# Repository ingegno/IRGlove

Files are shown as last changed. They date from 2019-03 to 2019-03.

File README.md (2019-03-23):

# IRGlove

Hier beschrijven een adaptatie van het GloveIR project van Phablabs: een handschoen om IR bestuurbare toestellen te controleren.

**English**: See [English Manual](README_EN.md) - Here we describe an adaptation of the GloveIR project of Phablabs: a glove to control IR enabled devices

## Base project

Het originele phablabs project vindt je hier terug: 

* [Phablabs.eu ir-glove project](http://phablabs.eu/workshop/ir-glove)
* [PDF Constructie handleiding](http://phablabs.eu/sites/default/files/Photonics%20IRglove_online_0.pdf)

De Code is gebaseerd op `record.ino` van [IRLib2](https://github.com/cyborg5/IRLib2) welke GPL v3 is, dus deze handleiding is ook onder Licentie GPL v3.

## Constructie
We doen volgende wijzigingen tov het Phalabs project
* gebruik Arduino Nano
* gebruik Arduino Nano houder
* componenten bevestigen rechtstreeks aan de Nano houder
* stand-alone versie: handschoen kan IR opnemen en afspelen zonder dat een PC nodig is

# Handleiding

## Constructie op Breadboad
Maak indien gewenst eerst de constructie op een breadboard. Daarna kun je al de code flashen naar de Arduino, en testen.

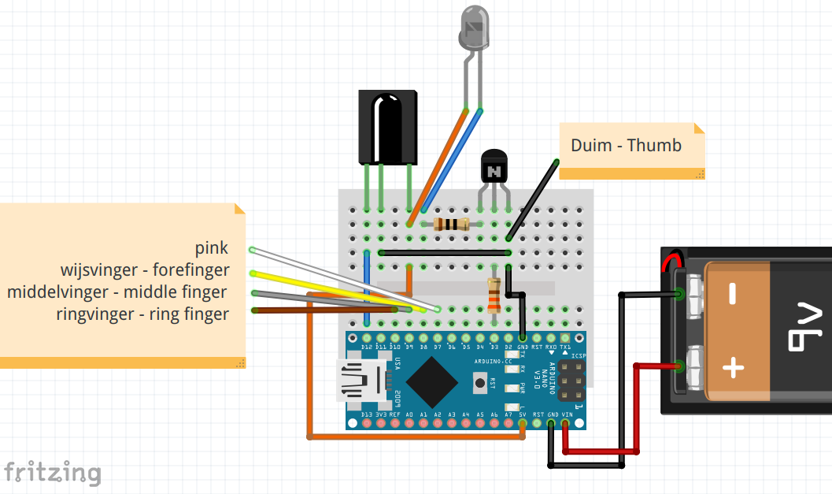
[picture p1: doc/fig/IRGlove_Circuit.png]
circuit


## Constructie Foto Handleiding

### Electronisch circuit

We beginnen met de electronica klaarmaken. 

**Stap 1** 

Plaats de Nano op de Nano houder. Zorg dat pinnen juist zitten !

Maak draden die met de handschoen zullen verbinden voor de 5 fingers. Connecteer dan als volgt

* duim: GND zoals op foto
* wijsvinger: D10
* middelvinger: D9
* ringvinger: D8
* pink: D7

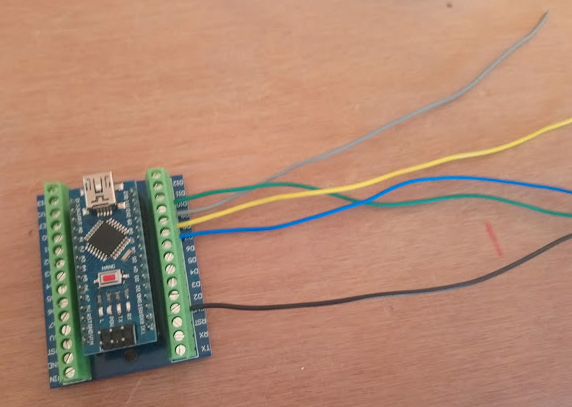
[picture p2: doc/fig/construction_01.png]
stap01


**Stap 2** 

De 9V batterijhouder connecteer je met Vin en GND aan de andere kant. Opgelet, Vin is **ROOD**.

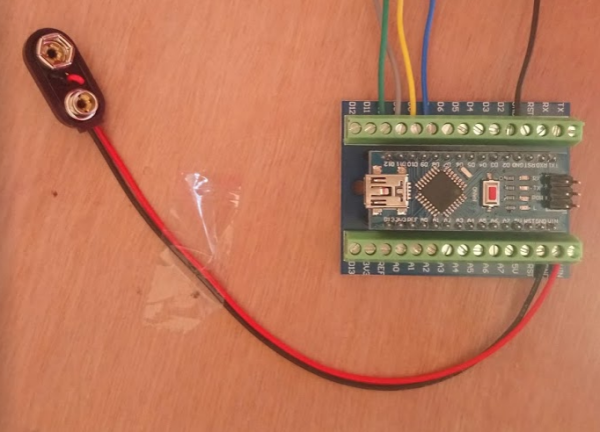
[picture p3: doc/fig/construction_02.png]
stap02


**Stap 3** 

Soldeer de 330 Ohm weerstand aan middelste beentje van de transistor zoals op de foto. Dus, aan de platte kant
van de transistor!

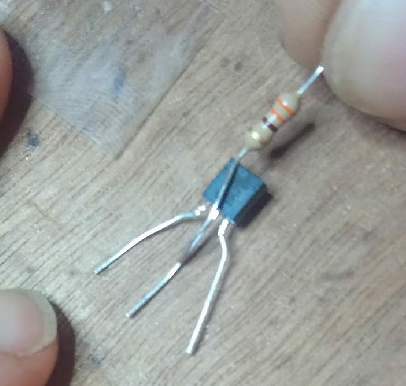
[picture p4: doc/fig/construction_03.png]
stap03


**Stap 4** 

Bescherm nu middelste beentje transistor met een krimpkous.

Aan de *linkerkant* (als je kijkt op platte kant transistor) soldeer je de 10 Ohm weerstand. En daaraan dan een draad
die lang genoeg is om tot aan de knokels van je hand te lopen.

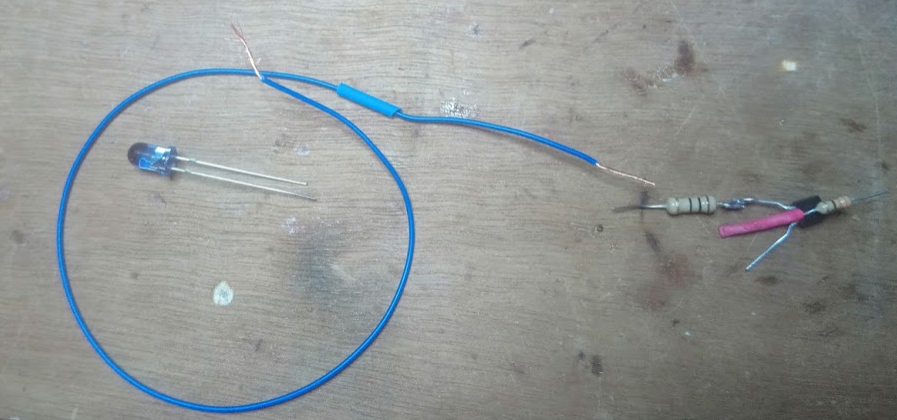
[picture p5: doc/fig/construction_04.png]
stap04


**Stap 5** 

Soldeer einde van die draad nu aan **korste** beentje van de IR LED (onze *zender*). Bescherm met krimpkous.

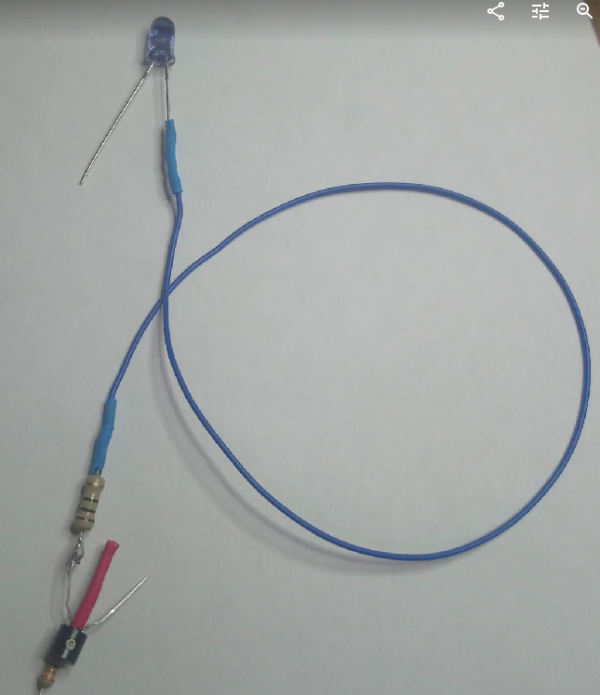
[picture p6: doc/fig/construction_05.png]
stap05


Het lange beentje van de IR LED is de +. Neem dan ook een **rode** draad, en soldeer hem eraan. Knip beentje LED
eerst wat korter dat je niet teveel krimpkous nodig hebt

**Stap 6** 

De rode draad van de IR LED stop je in de 5V van de NANO houder **samen** met **rechter** been van de IR ontvanger
(rechts als je kijkt naar de uitstulping).

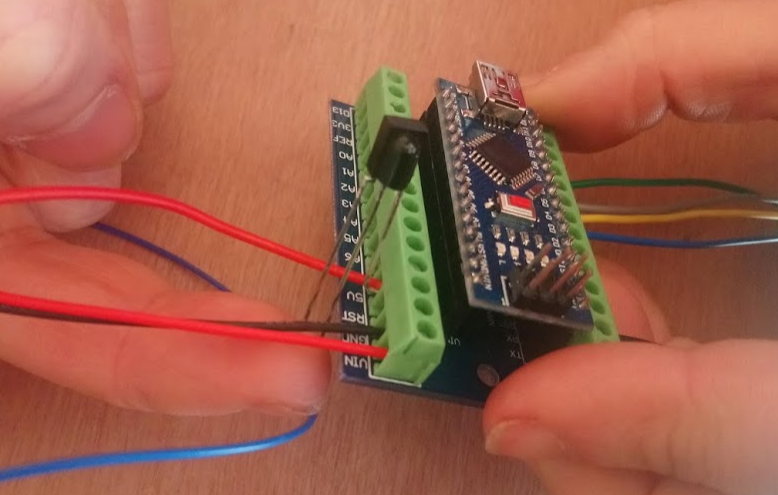
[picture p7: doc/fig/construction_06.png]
stap06


**Stap 7** 

Om kortsluiting te vermijden, doe krimpkous over bovenkant van middelste been IR ontvangen, en stop deze dan, na 
plooien in de GND van de Arduino houder

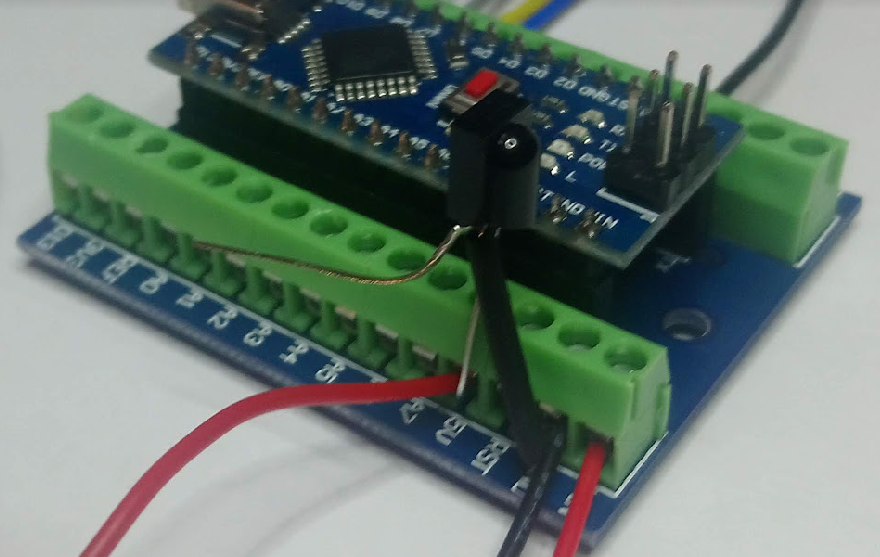
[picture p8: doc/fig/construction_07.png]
stap07


Buig linkse been IR ontvanger naar achter.

**Stap 8** 

Soldeer een draad aan linkse been IR ontvanger, en bevestig andere uiteinde aan pin D12.

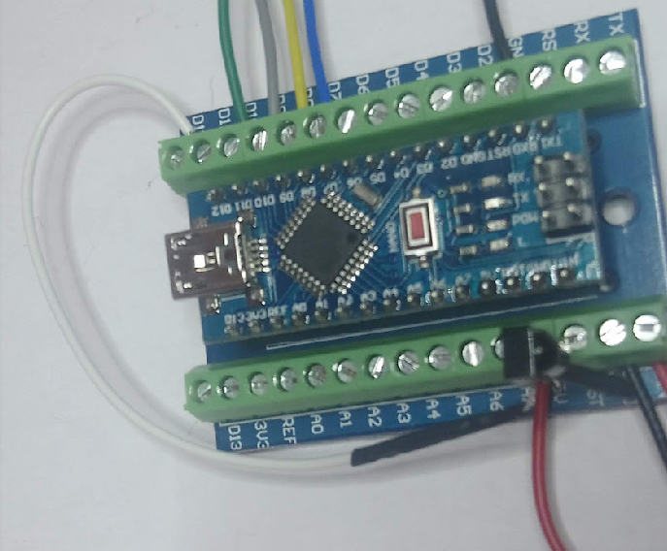
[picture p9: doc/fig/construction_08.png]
stap08


**Stap 9** 

Je hebt nu enkel nog de transistor die los zit. De *rechterkant* (als je kijkt op platte kant transistor) van de 
transistor moet in de GND, terwijl uiteinde van de 330 Ohm weerstand in pin D3 moet. Dat moet normaal
lukken zoals op volgende foto:

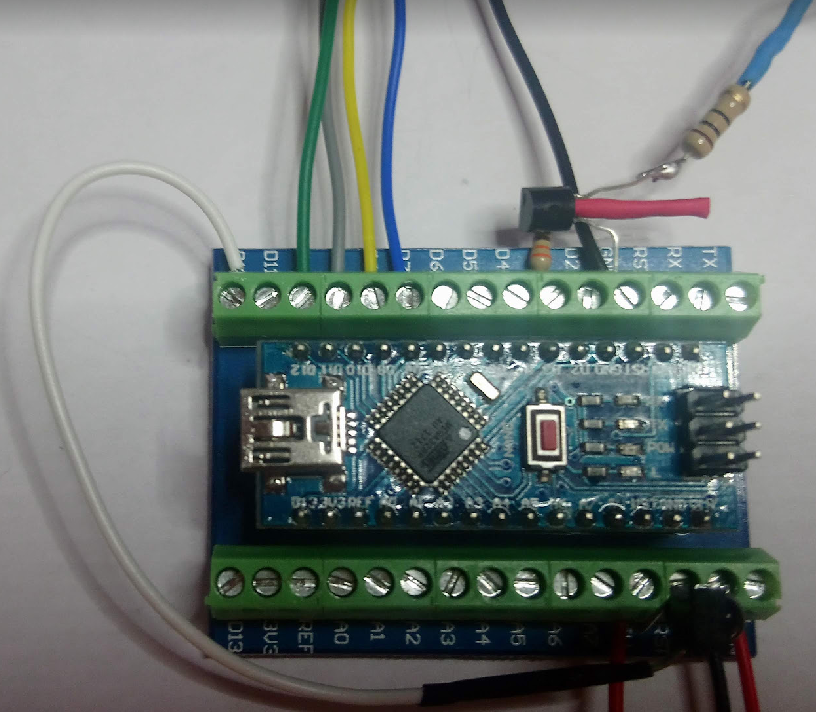
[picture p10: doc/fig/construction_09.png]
stap09


**Stap 10**
Je circuit is af. We moeten nu de vingers bevestigen aan de handschoen, en de IR LED plaatsen waar we signalen 
willen uitsturen. Het geheel zou er als volgt uit moeten zien:

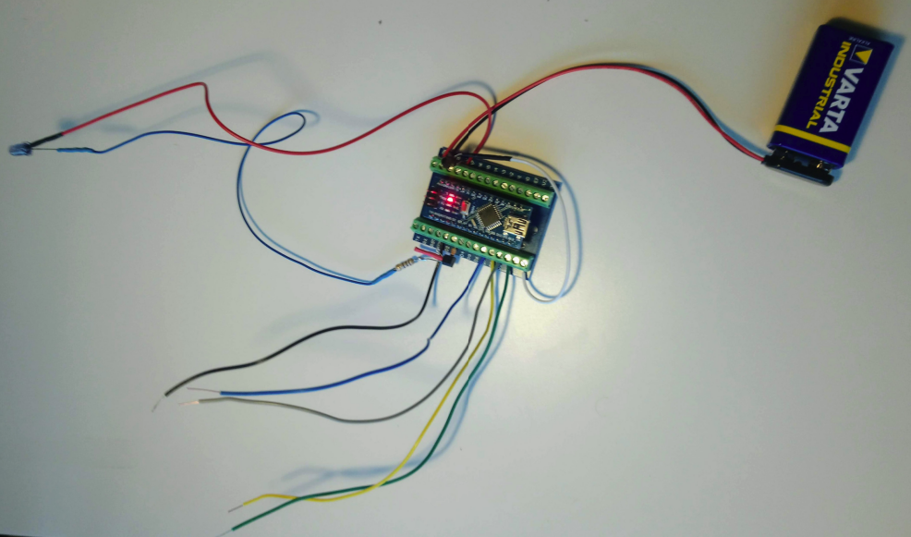
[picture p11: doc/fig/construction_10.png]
stap10


### Handschoen

De handschoen kun je nu maken of eerst de code installeren om te testen.

## Code Installeren

### Benodigdheden
Installeer op je computer de Arduino IDE 1.8.8. 

Installeer dan via de library manager (`CTRL+SHIFT+I`) volgende bibliotheek:
* EEPROMEx versie 1.0.0 van Thijs Elenbaas

Install EEPROMex

Vervolgens download via deze link [IRLib2](https://github.com/cyborg5/IRLib2) via de **Download Zip** knop (Wij gebruiken versie 3 Jun 2018). VOEG HIER SCREENSHOT TOE
Unzip de download, en kopieer **een deel** van de Download naar de Arduino library folder zodat deze volgende structuur heeft: 

    Arduino/libraries/IRLib2
    Arduino/libraries/IRLibFreq
    Arduino/libraries/IRLibProtocols
    Arduino/libraries/IRLibRecv
    Arduino/libraries/IRLibRecvPCI

Op Windows is dit normaal in locatie `C:\Users\USERNAME\Documents\Arduino`, op linux in `\home\USERNAME\Arduino`.

### IRGlove code - Standaard Code
#### Installatie
Download de code van deze git via de **Download zip** knop en unzip de download. 
Dubbel klik op de `IRGlove-master/IRGlove/IRGlove.ino` file in de unzipped code folder. Dit zal Arduino 1.8.8 openen op onze code. 

Selecteer als bord Arduino Nano. Druk op compileer om te code te verifieren. 

Krijg je de fout:

    lto1: internal compiler error: in lto_output_varpool_node, at lto-cgraph.c:624
    Please submit a full bug report,
    with preprocessed source if appropriate.

dan dien je oplossing uit [deze thread](https://forum.arduino.cc/index.php?topic=574020.0) uit te voeren als gevolg van bug [39](https://github.com/arduino/ArduinoCore-avr/issues/39):

    Tools > Board > Boards Manager
    Wait for downloads to finish. WAT IS DIT WACHTEN????
    When you move the mouse pointer over "Arduino AVR Boards", you will see a "Select version" dropdown menu appear. Select "1.6.21". SCREENSHOT
    Click "Install".
    Wait for installation to finish.
    Click "Close".

Na dit project kun je opnieuw de laatste versie van de *Arduino AVR Boards* installeren.

Laad de code op je Arduino Nano.

#### Werking Code
De code werkt volgens een *state machine*, in het Nederlands *Eindigetoestandsautomaat*. Is het de eerste keer dat je de code oplaad, dan moet je nog programmeren wat de vingers moeten doen. 

De toestanden van de code zijn als volgt:

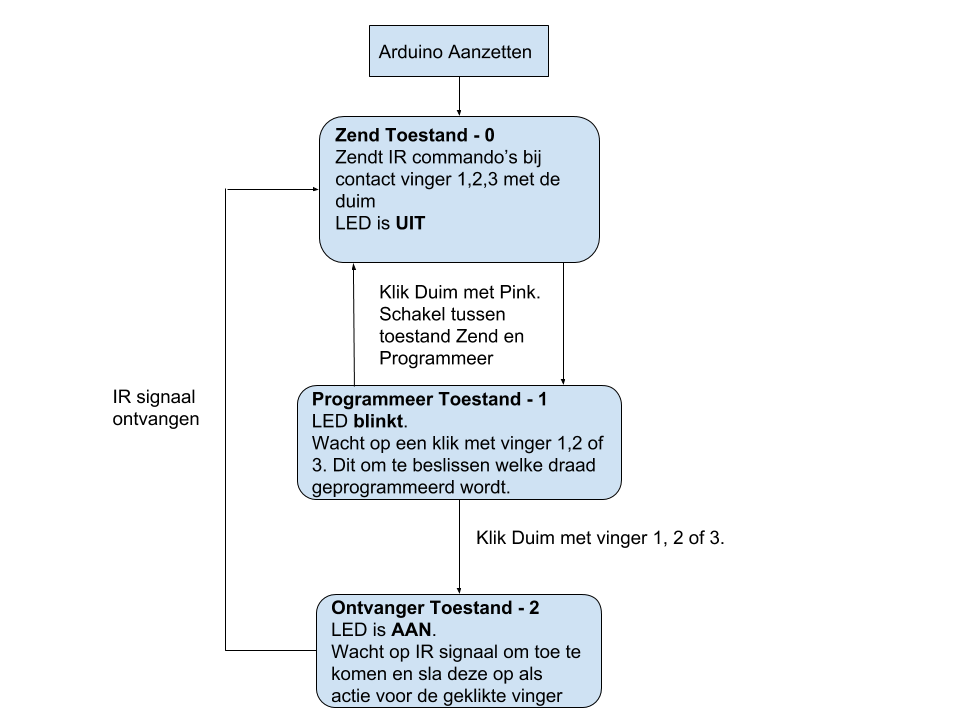
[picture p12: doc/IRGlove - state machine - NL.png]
finite state machine


Je gebruikt dus de pink (verbonden aan pin 7 van de Arduino) om tussen de toestanden te schakelen, kiest de vinger die je wil programmeren, en stuurt een IR bericht om dit op te slaat. Kijk naar de interne LED om te weten in welke toestand de Arduino Nano zich bevindt.

De LED is uit in de normale werking als codes uitgestuurd worden. Dit betekend dat enkel de POWER LED brandt:

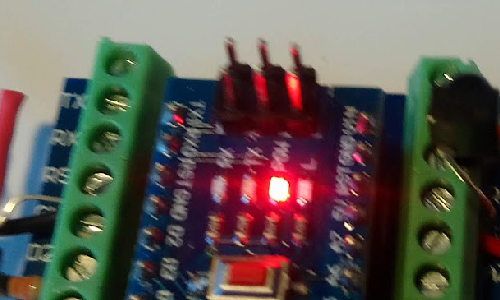
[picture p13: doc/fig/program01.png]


Terwijl gewacht wordt om een vinger te kiezen om te programmeren flikkert de LED aan en uit. Als er gewacht wordt op een IR code van een telecommando, zal de LED aan zijn.

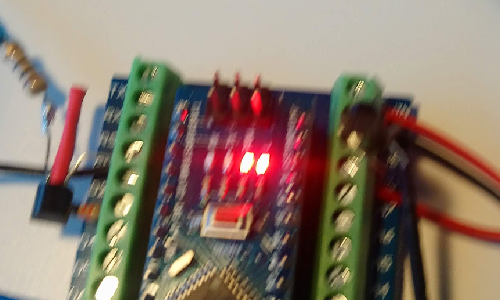
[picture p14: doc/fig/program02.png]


Zodra een code ontvangen is, schakelt de LED weer uit.

Wil je weten hoe deze eindigetoestandsautomaat geprogrammeerd werd? De basis werd in onze blokkencode gemaakt en dan geintegreerd in de code. Je kan de automaat bekijken via [onze blokkencode](http://blokkencode.ingegno.be/) waar je volgende xml moet opladen: [ProgramStates.xml](doc/ProgramStates.xml)

### IRGlove code - Test Code
#### Installatie
Download de code van deze git via de **Download zip** knop en unzip de download. 
Dubbel klik op de `IRGlove-master/IRGlove_SerialProgrammed/IRGlove_SerialProgrammed.ino` file in de unzipped code folder. Dit zal Arduino 1.8.8 openen op onze code. 

Selecteer als bord Arduino Nano. Druk op compileer om te code te verifieren. 

Krijg je de fout:

    lto1: internal compiler error: in lto_output_varpool_node, at lto-cgraph.c:624
    Please submit a full bug report,
    with preprocessed source if appropriate.

volg dan de oplossing hierboven gegeven bij standaard code.

#### Werking
Bij de test code hou je de Arduino Nano verbonden met de PC, en open je de Seriele monitor. Je kan via de seriele monitor de opdracht doorgeven om IR signalen op te slaan. Je krijgt feedback op de seriele monitor van ontvangen IR codes en uitgestuurde IR codes. Dit helpt je in begrijpen of een bepaalde IR code correct geinterpreteerd wordt door de code.

Merk op dat dit deel van de code ook beschikbaar is in de standaard code. Om de seriele monitor aan te schakelen voor de standaard code dien je enkel volgende lijn te zoeken in de `.ino` file

    // set serial output on or off
    #define TEST_WITH_SERIAL false

en wijzigen in 

    // set serial output on or off
    #define TEST_WITH_SERIAL true

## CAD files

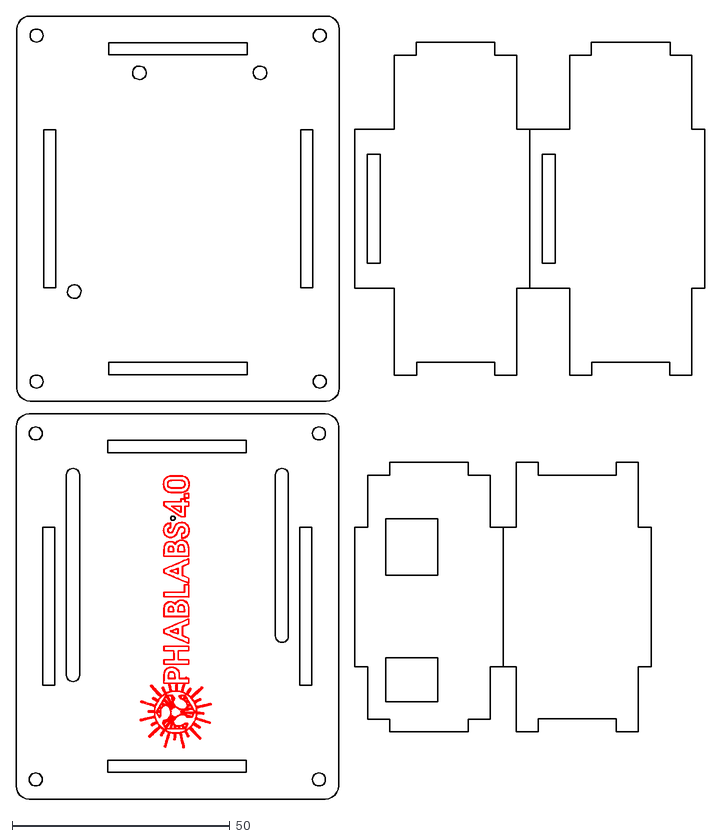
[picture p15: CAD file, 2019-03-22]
case/gloveIR case_UNO.dxf
158.2 x 179.9

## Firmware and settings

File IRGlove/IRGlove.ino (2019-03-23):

/* Based on record.ino Example sketch from IRLib2 - GPL v3
 *  Adapted by VUB http://phablabs.eu/workshop/ir-glove 
 *  Adapted by Ingegno Maker Space in https://github.com/ingegno/IRGlove:
 *      - fix bugs
 *      - correct store of signals
 *      
*/

/*  USER SETTINGS 
 *   
*/
// board selection
#define B_UNO 0
#define B_NANO 1
// do you use an UNO or a NANO for the glove ? 
#define IRGLOVE_BOARD B_NANO

// select language
#define LANG_EN 0
#define LANG_NL 1
// select language of the output in serial monitor
#define LANG_OUTPUT LANG_NL

// set the fingers you will use
const int COUNT = 3;
const String vinger_EN[COUNT] = {"forefinger", "middle finger", "ring finger"};
const String vinger[COUNT] = {"wijsvinger", "middelvinger", "ringvinger"};
// pins on the Arduino for the fingers:
const int INPUTS[COUNT] = {8, 9, 10};

// optional pin to program
const int PROGRAM_PIN = 7;

// pin used by the IR receiver
const int IR_RECEIVE_PIN = 12;

// pin used by the IR sender is based on your hardware. UNO and NANO are pin 3
// for other boards look up the pin in IRLibProtocols/IRLibHardware.h of the library!

// pin with LED output to indicate programming state or not. Default is builtinLED pin 13
const int builtInLed = 13;

// set serial output on or off
#define TEST_WITH_SERIAL false

/*  CODE 
 *   
*/
int program_state;
const int programbtn = PROGRAM_PIN;
boolean builtInLed_ON = HIGH;
// there must be at least one finger. In setup we correct this if more!
int finger1 = INPUTS[0];
int finger2 = INPUTS[0];
int finger3 = INPUTS[0];

boolean programbtn_PRESSED = LOW;

boolean finger1_PRESSED = LOW;

boolean finger2_PRESSED = LOW;

boolean finger3_PRESSED = LOW;

const int maxAllowedWrites = 80;
// start reading from the first byte (address 120) of the EEPROM
const int memBase          = 120;

#include <EEPROMex.h>
#include <EEPROMVar.h>

#include <IRLibDecodeBase.h>  //We need both the coding and
#include <IRLibSendBase.h>    // sending base classes
#include <IRLib_P01_NEC.h>    //Lowest numbered protocol 1st
#include <IRLib_P02_Sony.h>   // Include only protocols you want
#include <IRLib_P03_RC5.h>
#include <IRLib_P04_RC6.h>
#include <IRLib_P05_Panasonic_Old.h>
#include <IRLib_P07_NECx.h>
#include <IRLib_HashRaw.h>    //We need this for IRsendRaw
#include <IRLibCombo.h>       // After all protocols, include this
// All of the above automatically creates a universal decoder
// class called "IRdecode" and a universal sender class "IRsend"
// containing only the protocols you want.
// Now declare instances of the decoder and the sender.

IRdecode myDecoder;
IRsend mySender;

// Include a receiver either this or IRLibRecvPCI or IRLibRecvLoop
#include <IRLibRecv.h>
IRrecv myReceiver(IR_RECEIVE_PIN); //pin number for the receiver

int programCode = 0;

// Storage for the recorded code
uint8_t codeProtocol[COUNT] = {0};  // The type of code
uint32_t codeValue[COUNT] = {0};    // The data bits if type is not raw
uint8_t codeBits[COUNT] = {0};      // The length of the code in bits

long programbtnbuttonTimer = 0;
#define programbtnminShortPressTime 80
#define programbtnlongPressTime 750
boolean programbtnbuttonActive = false;
boolean programbtnlongPressActive = false;
#define programbtnNOPRESS    0
#define programbtnSHORTPRESS 1
#define programbtnLONGPRESS  2
int programbtnPressType = programbtnNOPRESS;
long finger1buttonTimer = 0;
#define finger1minShortPressTime 80
#define finger1longPressTime 750
boolean finger1buttonActive = false;
boolean finger1longPressActive = false;
#define finger1NOPRESS    0
#define finger1SHORTPRESS 1
#define finger1LONGPRESS  2
int finger1PressType = finger1NOPRESS;
long finger2buttonTimer = 0;
#define finger2minShortPressTime 80
#define finger2longPressTime 750
boolean finger2buttonActive = false;
boolean finger2longPressActive = false;
#define finger2NOPRESS    0
#define finger2SHORTPRESS 1
#define finger2LONGPRESS  2
int finger2PressType = finger2NOPRESS;
long finger3buttonTimer = 0;
#define finger3minShortPressTime 80
#define finger3longPressTime 750
boolean finger3buttonActive = false;
boolean finger3longPressActive = false;
#define finger3NOPRESS    0
#define finger3SHORTPRESS 1
#define finger3LONGPRESS  2
int finger3PressType = finger3NOPRESS;

int ard_effect0_status = -1;
unsigned long ard_effect0_start, ard_effect0_time;
#define EFFECT0_PERIOD 500
#define EFFECT0_1_DURATION 250

void setup() {
  // start reading from position memBase (address 0) of the EEPROM. Set maximumSize to EEPROMSizeUno 
  // Writes before membase or beyond EEPROMSize will only give errors when _EEPROMEX_DEBUG is set
  if (IRGLOVE_BOARD == B_NANO) {
    EEPROM.setMemPool(memBase, EEPROMSizeNano);
  } else {
    EEPROM.setMemPool(memBase, EEPROMSizeUno);
  }
  // Set maximum allowed writes to maxAllowedWrites. 
  // More writes will only give errors when _EEPROMEX_DEBUG is set
  EEPROM.setMaxAllowedWrites(maxAllowedWrites);
  delay(100);
  
  if (TEST_WITH_SERIAL) {
    Serial.begin(9600);
    
    while (!Serial) {
      ; // wait for serial port to connect. Needed for native USB port only
    }
  }
  
  // obtain last stored values from EEPROM memory after startup
  for (int i = 0; i < COUNT; i++) {
    pinMode(INPUTS[i], INPUT_PULLUP);
    //read in stored data from EEPROM
    codeValue[i] = EEPROM.readLong(i*50);
    codeBits[i] = EEPROM.readByte((i*50)+32);
    codeProtocol[i] = EEPROM.readByte((i*50)+40);
    
    if (TEST_WITH_SERIAL) {
      if (LANG_OUTPUT == LANG_NL) Serial.println("Gevonden commando's in EEPROM:");
      else Serial.println("Found commands in EEPROM:");
      Serial.print(i+1);Serial.print(" ");Serial.print(codeProtocol[i]);
      Serial.print(" 0x");Serial.print(codeValue[i], HEX);
      Serial.print(", bits 0x");Serial.println(codeBits[i], HEX);
    }
  }
  // Program pin is a pushbutton or the pinky
  pinMode(PROGRAM_PIN, INPUT_PULLUP);

  if (TEST_WITH_SERIAL) displayMenu();
  
  if (COUNT > 1) {finger2 = INPUTS[1];}
  if (COUNT > 2) finger3 = INPUTS[2];
  
  ard_effect0_status = -1;
  ard_effect0_start = millis();

  digitalWrite(builtInLed, ! (builtInLed_ON));
  program_state = 0;
}

void displayMenu() {
  Serial.println("GloveIR STEAMbox menu");
  Serial.println("*********************");
  for (int i = 0; i < COUNT; i++) {
    if (LANG_OUTPUT == LANG_NL) {
      Serial.print("Stuur via deze monitor nummer ");
      Serial.print(i+1);
      Serial.print(", om de code voor de ");
      Serial.print(vinger[i]);
      Serial.println(" op te nemen.");
    } else {
      Serial.print("Send via this monitor number ");
      Serial.print(i+1);
      Serial.print(", to record the code for the ");
      Serial.print(vinger_EN[i]);
      Serial.println(".");
    }
  }
  Serial.println();
}
void flickerLED() {
  //Variables of this effect are reffered to with ard_effect0
  boolean restart = false;
  ard_effect0_time = millis() - ard_effect0_start;
  if (ard_effect0_time > EFFECT0_PERIOD) {
    //end effect, make sure it restarts
    if (ard_effect0_status > -1) {
    }
    restart = true;
    ard_effect0_status = -1;
    ard_effect0_start = ard_effect0_start + ard_effect0_time;
    ard_effect0_time = 0;
  }
  if (not restart && ard_effect0_status == -1) {
    ard_effect0_status = 0;
    ard_effect0_start = ard_effect0_start + ard_effect0_time;
    ard_effect0_time = 0;
  digitalWrite(builtInLed, builtInLed_ON);
  }
  if (ard_effect0_time > EFFECT0_1_DURATION && ard_effect0_status < 1) {
   ard_effect0_status = 1;
  digitalWrite(builtInLed, ! (builtInLed_ON));
  }
}

void normalState() {
  if (TEST_WITH_SERIAL) {
    // one can set commands using serial monitor input
    if (Serial.available() > 0) {
      programCode = Serial.parseInt();   // returns 0 on failure/timeout!
      if (programCode >= 1 && programCode <= COUNT ) {
        if (LANG_OUTPUT == LANG_NL) Serial.print("Ontvangen ");
        else Serial.print("Received ");
        Serial.println(programCode);
        programActionForVinger(programCode-1);
        displayMenu();
      }
    }
  }
  
  // react if a button (=closing finger) is pushed
  processInputs();
}

void handleprogrambtnPress() {
  programbtnPressType = programbtnNOPRESS;
      if (digitalRead(programbtn) == programbtn_PRESSED) {
        if (programbtnbuttonActive == false) {
          programbtnbuttonActive = true;
          programbtnbuttonTimer = millis();
        }
        if ((millis() - programbtnbuttonTimer > programbtnlongPressTime) && (programbtnlongPressActive == false)) {
          programbtnlongPressActive = true;
          programbtnPressType = programbtnLONGPRESS;
        }
      } else {
        if (programbtnbuttonActive == true) {
          if (programbtnlongPressActive == true) {
            programbtnlongPressActive = false;
          } else {
            //avoid fast fluctuations to be identified as a click
            if (millis() - programbtnbuttonTimer > programbtnminShortPressTime)
              programbtnPressType = programbtnSHORTPRESS;
          }
          programbtnbuttonActive = false;
        }
      }
}



void handlefinger1Press() {
  finger1PressType = finger1NOPRESS;
      if (digitalRead(finger1) == finger1_PRESSED) {
        if (finger1buttonActive == false) {
          finger1buttonActive = true;
          finger1buttonTimer = millis();
        }
        if ((millis() - finger1buttonTimer > finger1longPressTime) && (finger1longPressActive == false)) {
          finger1longPressActive = true;
          finger1PressType = finger1LONGPRESS;
        }
      } else {
        if (finger1buttonActive == true) {
          if (finger1longPressActive == true) {
            finger1longPressActive = false;
          } else {
            //avoid fast fluctuations to be identified as a click
            if (millis() - finger1buttonTimer > finger1minShortPressTime)
              finger1PressType = finger1SHORTPRESS;
          }
          finger1buttonActive = false;
        }
      }
}



void handlefinger2Press() {
  finger2PressType = finger2NOPRESS;
      if (digitalRead(finger2) == finger2_PRESSED) {
        if (finger2buttonActive == false) {
          finger2buttonActive = true;
          finger2buttonTimer = millis();
        }
        if ((millis() - finger2buttonTimer > finger2longPressTime) && (finger2longPressActive == false)) {
          finger2longPressActive = true;
          finger2PressType = finger2LONGPRESS;
        }
      } else {
        if (finger2buttonActive == true) {
          if (finger2longPressActive == true) {
            finger2longPressActive = false;
          } else {
            //avoid fast fluctuations to be identified as a click
            if (millis() - finger2buttonTimer > finger2minShortPressTime)
              finger2PressType = finger2SHORTPRESS;
          }
          finger2buttonActive = false;
        }
      }
}

void handlefinger3Press() {
  finger3PressType = finger3NOPRESS;
      if (digitalRead(finger3) == finger3_PRESSED) {
        if (finger3buttonActive == false) {
          finger3buttonActive = true;
          finger3buttonTimer = millis();
        }
        if ((millis() - finger3buttonTimer > finger3longPressTime) && (finger3longPressActive == false)) {
          finger3longPressActive = true;
          finger3PressType = finger3LONGPRESS;
        }
      } else {
        if (finger3buttonActive == true) {
          if (finger3longPressActive == true) {
            finger3longPressActive = false;
          } else {
            //avoid fast fluctuations to be identified as a click
            if (millis() - finger3buttonTimer > finger3minShortPressTime)
              finger3PressType = finger3SHORTPRESS;
          }
          finger3buttonActive = false;
        }
      }
}
void programState() {
  handlefinger1Press();

  if (finger1PressType == finger1SHORTPRESS) {
    //START STATEMENTS SHORT PRESS
    program_state = 2;
    
    if (TEST_WITH_SERIAL) {
      if (LANG_OUTPUT == LANG_NL)  Serial.println("vinger 1 geklikt, programmeer hem nu");
      else  Serial.println("finger 1 clicked, program it now");
    }
    
    //END  STATEMENTS SHORT PRESS
  } else if (finger1PressType == finger1LONGPRESS) {
    //START STATEMENTS LONG PRESS
    //END  STATEMENTS LONG PRESS
  } else if (!finger1longPressActive && digitalRead(finger1) == finger1_PRESSED) {
    //START STATEMENTS PRESS
    //END  STATEMENTS PRESS
  }

  if (COUNT > 1) {
    handlefinger2Press();
  
    if (finger2PressType == finger2SHORTPRESS) {
      //START STATEMENTS SHORT PRESS
      program_state = 3;
      if (TEST_WITH_SERIAL) {
        if (LANG_OUTPUT == LANG_NL)  Serial.println("vinger 2 geklikt, programmeer hem nu");
        else  Serial.println("finger 2 clicked, program it now");
      }
      //END  STATEMENTS SHORT PRESS
    } else if (finger2PressType == finger2LONGPRESS) {
      //START STATEMENTS LONG PRESS
      //END  STATEMENTS LONG PRESS
    } else if (!finger2longPressActive && digitalRead(finger2) == finger2_PRESSED) {
      //START STATEMENTS PRESS
      //END  STATEMENTS PRESS
    }
  }


  if (COUNT > 2) {
  handlefinger3Press();
  
    if (finger3PressType == finger3SHORTPRESS) {
      //START STATEMENTS SHORT PRESS
      program_state = 4;
      if (TEST_WITH_SERIAL) {
        if (LANG_OUTPUT == LANG_NL)  Serial.println("vinger 3 geklikt, programmeer hem nu");
        else  Serial.println("finger 3 clicked, program it now");
      }
      //END  STATEMENTS SHORT PRESS
    } else if (finger3PressType == finger3LONGPRESS) {
      //START STATEMENTS LONG PRESS
      //END  STATEMENTS LONG PRESS
    } else if (!finger3longPressActive && digitalRead(finger3) == finger3_PRESSED) {
      //START STATEMENTS PRESS
      //END  STATEMENTS PRESS
    }
  }

}

void loop() {
  
  handleprogrambtnPress();

  if (programbtnPressType == programbtnSHORTPRESS) {
    //START STATEMENTS SHORT PRESS
    if (program_state == 0) {
      program_state = 1;
    } else if (program_state == 1) {
      program_state = 0;
    }
    //END  STATEMENTS SHORT PRESS
  } else if (programbtnPressType == programbtnLONGPRESS) {
    //START STATEMENTS LONG PRESS
    //END  STATEMENTS LONG PRESS
  } else if (!programbtnlongPressActive && digitalRead(programbtn) == programbtn_PRESSED) {
    //START STATEMENTS PRESS
    //END  STATEMENTS PRESS
  }

  if (program_state == 0) {
    digitalWrite(builtInLed, ! (builtInLed_ON));
    normalState();
  } else if (program_state == 1) {
    flickerLED();
    programState();
  } else if (program_state == 2) {
    digitalWrite(builtInLed, builtInLed_ON);
    programActionForVinger(0);
    program_state = 0;
  } else if (program_state == 3) {
    digitalWrite(builtInLed, builtInLed_ON);
    programActionForVinger(1);
    program_state = 0;
  } else if (program_state == 4) {
    digitalWrite(builtInLed, builtInLed_ON);
    programActionForVinger(2);
    program_state = 0;
  }
}

void programActionForVinger(int code) {
  // we make us ready to receive signals
  myReceiver.enableIRIn(); // Start the receiver. This uses interrupt code, so we can use delay!
  delay(1000);
  
  if (TEST_WITH_SERIAL) {
    // we write on Serial what user has to do
    if (LANG_OUTPUT == LANG_NL)  Serial.println("Houd de IR-afstandsbediening voor de ontvanger en druk je commando in..");
    else  Serial.println("Hold the IR-remote in front of the receiver and press the button with your command..");
  }
  // loop tot resultaten binnen zijn
  do {
    delay(1000);
    if (TEST_WITH_SERIAL) {
      if (LANG_OUTPUT == LANG_NL)  Serial.println("Nog niets ontvangen");
      else Serial.println("Nothing received yet...");
    }
  } while (!myReceiver.getResults());
  // decodeer signaal
  myDecoder.decode();
  // sla signaal op
  storeCode(code);
  if (TEST_WITH_SERIAL) {
    if (LANG_OUTPUT == LANG_NL)  Serial.print("Code opgeslagen als signaal: ");
    else Serial.print("Code saved as signal: ");
    Serial.println(code+1);
  }
}


// Stores the code for later playback
void storeCode(int codeIndex) {
  //gotNew = true;    gotOne = true;
  codeProtocol[codeIndex] = myDecoder.protocolNum;
  if (TEST_WITH_SERIAL) {
    if (LANG_OUTPUT == LANG_NL) Serial.print(F("Ontvangen "));
    else Serial.print(F("Received "));
    Serial.print(Pnames(codeProtocol[codeIndex]));
  }
  
  if (codeProtocol[codeIndex] == UNKNOWN) {
    if (TEST_WITH_SERIAL) {
      // print out the data
      if (LANG_OUTPUT == LANG_NL) Serial.println(F(" ruwe data opgelagen."));
      else Serial.println(F(" saving raw data."));
      myDecoder.dumpResults();
    }

    //clean up data as needed
    //The raw time values start in decodeBuffer[1] because
    //the [0] entry is the gap between frames. The address
    //is passed to the raw send routine.
    codeValue[codeIndex] = (uint32_t) & (recvGlobal.decodeBuffer[1]);
    //This isn't really number of bits. It's the number of entries
    //in the buffer.
    codeBits[codeIndex] = recvGlobal.decodeLength - 1;
    //updaten van EEPROM
    EEPROM.updateLong(codeIndex*50, codeValue[codeIndex]);
    EEPROM.updateByte((codeIndex*50)+32, codeBits[codeIndex]);
    EEPROM.updateByte((codeIndex*50)+40, codeProtocol[codeIndex]);
  }
  else {
    if (myDecoder.value == REPEAT_CODE) {
      // Don't record a NEC repeat value as that's useless.
      if (TEST_WITH_SERIAL) {
        if (LANG_OUTPUT == LANG_NL)  Serial.println(F("herhalingscommando; genegeerd."));
        else Serial.println(F("repeat; ignoring."));
      }
    } else {
      codeValue[codeIndex] = myDecoder.value;
      codeBits[codeIndex] = myDecoder.bits;
      //Updaten van EEPROM
      EEPROM.updateLong(codeIndex*50, codeValue[codeIndex]);
      EEPROM.updateByte((codeIndex*50)+32, codeBits[codeIndex]);
      EEPROM.updateByte((codeIndex*50)+40, codeProtocol[codeIndex]);
    }
    if (TEST_WITH_SERIAL) {
      Serial.print(F(" Value:0x"));
      Serial.println(myDecoder.value, HEX);
    }
  }
}


void processInputs() {
  for (int i = 0; i < COUNT; i++) {
    if (digitalRead(INPUTS[i]) == LOW) {
      if (TEST_WITH_SERIAL) {
        if (LANG_OUTPUT == LANG_NL)  Serial.print("Stuur nu code ");
        else Serial.print("Sending out code ");
        Serial.println(i+1);
      }
      sendCode(i);
      delay(100);
    }
  }
}
void sendCode(int codeIndex) {
  // send the raw data we stored!
  mySender.send(codeProtocol[codeIndex], codeValue[codeIndex], codeBits[codeIndex]);
  if (TEST_WITH_SERIAL) {
    if (LANG_OUTPUT == LANG_NL) Serial.print(F("Stuurde "));
    else Serial.print(F("Sent "));
    if (codeProtocol[codeIndex] != UNKNOWN) Serial.print(Pnames(codeProtocol[codeIndex]));
    if (LANG_OUTPUT == LANG_NL) Serial.print(F(" Waarde:0x"));
    else Serial.print(F(" Value:0x"));
    Serial.println(codeValue[codeIndex], HEX);
  }
}

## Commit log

2019-03-20 bugfix: on error reading integer from serial, don't assign finger
    [IRGlove.ino]
2019-03-20 Add a program pin to program the buttons
2019-03-21 correctly store known protocols
    [IRGlove.ino]
2019-03-22 Give doc in Arduino code
2019-03-22 make a fritzing circuit of glove
    [IRGlove.fzz]
2019-03-22 Fritzing drawing of circuit
    [IRGlove.fzz]
2019-03-22 add circuit
2019-03-22 Finished version * Correct storing in EEPROM * Dutch or English * UNO or NANO
    [IRGlove.ino]
2019-03-22 Original UNO case
    [gloveIR case_UNO.dxf]
2019-03-22 Work with program states state 0: send codes on finger touched with thumb if pink touched: switch to program mode: state 1 state 1: select finger to program. 3 fingers lead to state 2,3&4 state 2,3,4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
2019-03-23 Final version code * record and play with the glove, feedback via internal LED * bugfix: hide all serial behind flag
    [IRGlove.ino, IRGlove_SerialProgrammed.ino]
2019-03-23 Bugfix: error in circuit, wrong finger pin pink
    [IRGlove.fzz]
